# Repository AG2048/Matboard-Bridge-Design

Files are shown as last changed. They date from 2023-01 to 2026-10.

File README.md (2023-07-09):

# Matboard-Bridge-Design

Matboard bridge project for CIV102 - Structure and Material

For the final project of CIV102, students have to design a matboard bridge using limited materials. 

For this project, I developed the python code that models the bridge and calculates the failure load and thus the factor of safety. 

Inside the repository also includes the design report (which includes the designing and construction process), as well as the engineering drawings of the bridge.

For further information, https://civmin.utoronto.ca/bridge-testing-day-in-civ102-video/ includes the testing day of the bridge. (As of Jan 10 2023, the website only contains the testing information for 2021)

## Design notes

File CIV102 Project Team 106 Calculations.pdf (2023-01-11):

n | i

t

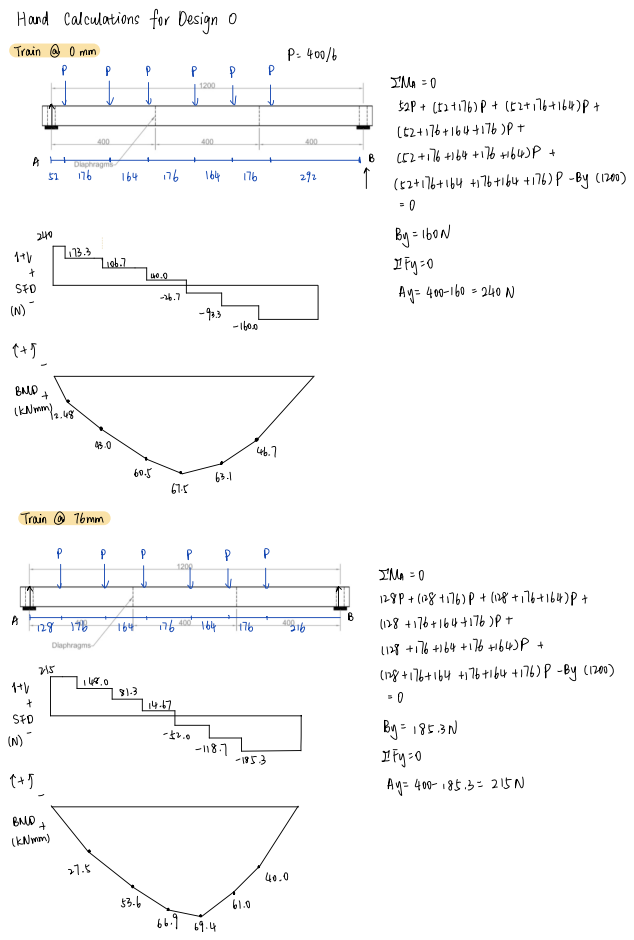
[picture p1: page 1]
Train 0mm; P ⁴⁰⁰6; SMA o; 528 15241761Pt152¹⁷⁶164Pt at; 152¹⁷⁶164176 Pt; gyp; 52176164 176164 176P By ¹²⁰⁰ D By¹⁶⁰N; IFyO; Ay⁴⁰⁰¹⁶⁰ ²⁴⁰N; boo; Mummies; Train 76mm; IMA O; B agent 1281176 164 176 164 176; Ay⁴⁰⁰¹⁸⁵.3 215N; Mimi; est

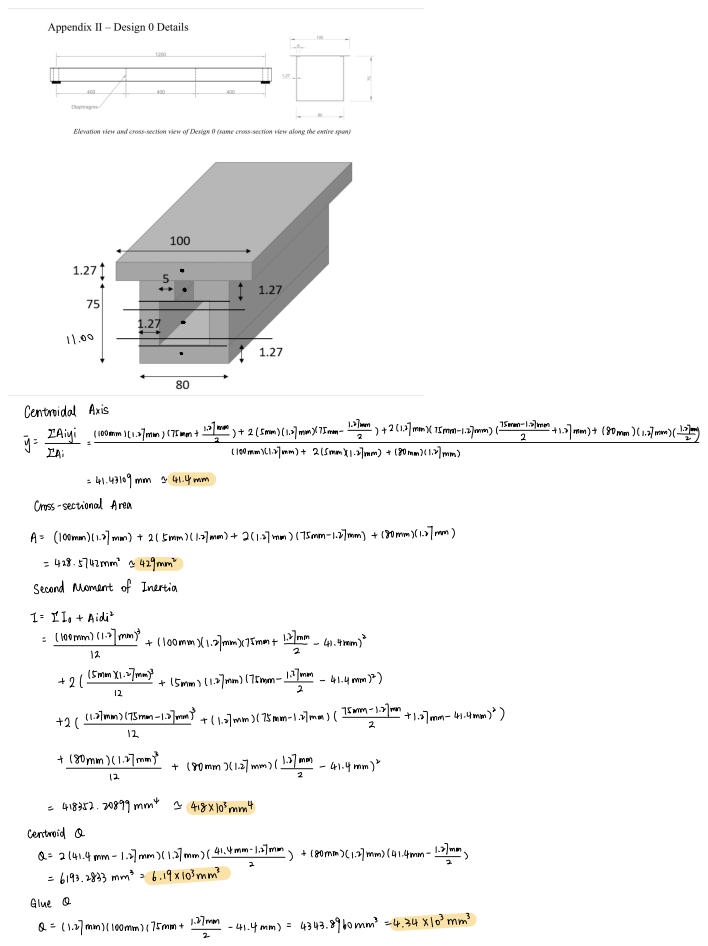
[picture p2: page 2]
entroidalAxis; cloommici 7mmit ²¹⁵mmiiiMmm isommici7mm; CrosssectionalArea; 7mm t 215mm 1.7mm 211.27mm175mm1.27mm isommill7mm; 428.5742mm a429mm secondMomentofInertia; IotAidi; 2 15mmill7mm is; 15mm 1.27mm175mm Imm 41.4mmp; 2 11.27mm lymm; gomm 1.27mm1171M 41.4mm; Centroid a a 2141.4mm 1.27mm 1.27mm 41.4mm l; Mmm; isommsci.ymmscai.amm t; Imm 2; 6193.2833mm 6.19103mm Glue a; 0 114mmilloomm175mm 12mm 41.4mm 4343.8960mm 4.34¹⁰³mm

175mmt Hamm 215mm111.4mm¹⁷⁵mm hmm 211.4mm1175mm1.27mm175mmt.mmtt.ymmitisommsci.ymmyl.my 2

ftp.iyi.lioommici.olmm

lloommsli.ofmmsatmmtt.LI 41.4mm

## as.am

### comp6hPa Tglue2hPa

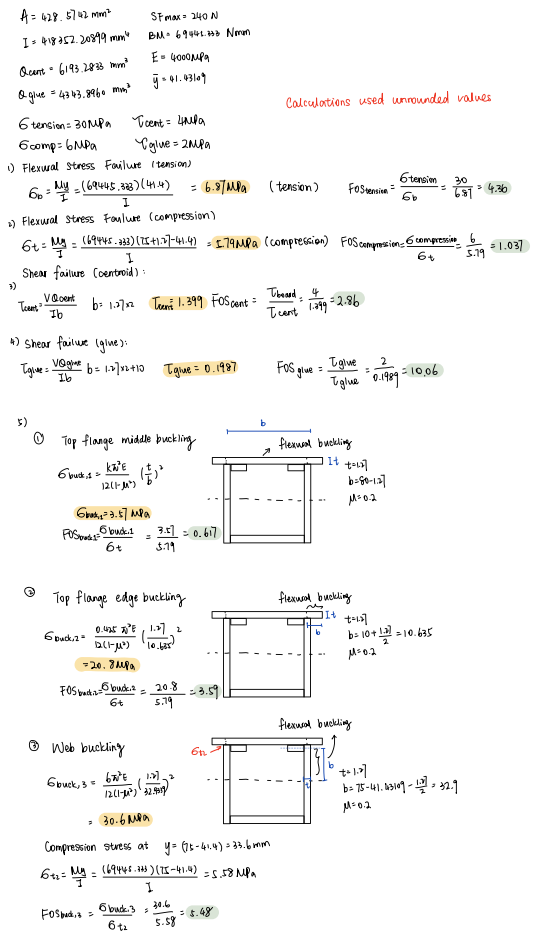
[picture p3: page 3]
BM⁶⁹⁴⁴⁵.333Nmm; E 4000hPa; I Acent 6193.2833mm; calculationsusedunroundedvalues; 6tension30hPa Tent 4hPa; 6 My169445.333714147 6.87hPa tension; Fostension; 6tension; a FlexuralstressFailure compression; 1.274141 5.79Mpa compression FOScompression6compression Eg ¹.037; Shearfailure centroid; Yg vÉg b; no igneous; insane Ige Easy10.06; topflangemiddlebuckling; flexuralbuckling; broin bucketEYEIf; It tan; Guns3.57hPa; FOSbuck.iq; may; back 1411 I p; byb; 20.8hPa www.qq; Webb; bas⁴¹.43109 Gun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

## toEYEfifiteal salma

### K5 a ³⁸⁵6 751.7

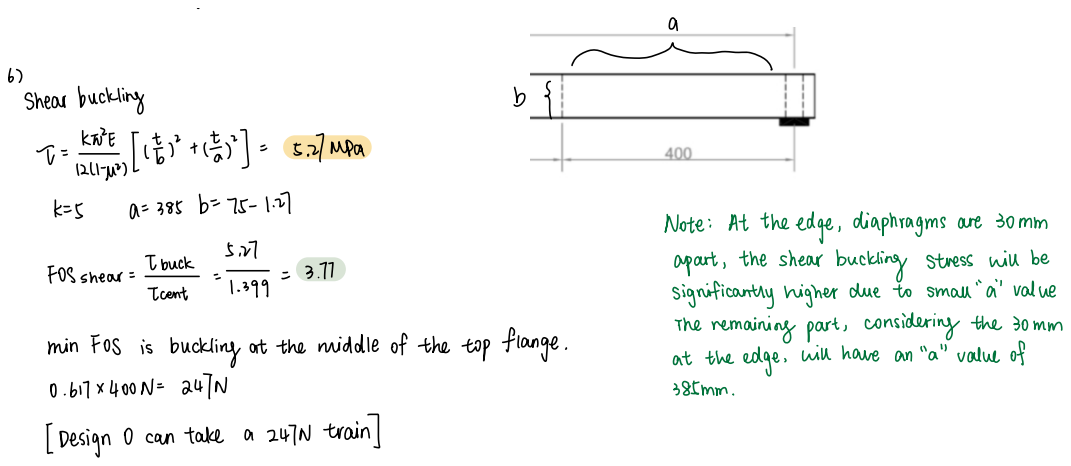
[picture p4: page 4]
shearbuckling; aparttheshearbuckling stresswillbe IOSshearIink; significantlyhigherduetosmall a value; Theremainingpart consideringthe30mm; minFos is bucklingatthemiddleofthetopflange; attheedgewinhavean a valueof

# Computer Output For Design 0

## Computer Output:

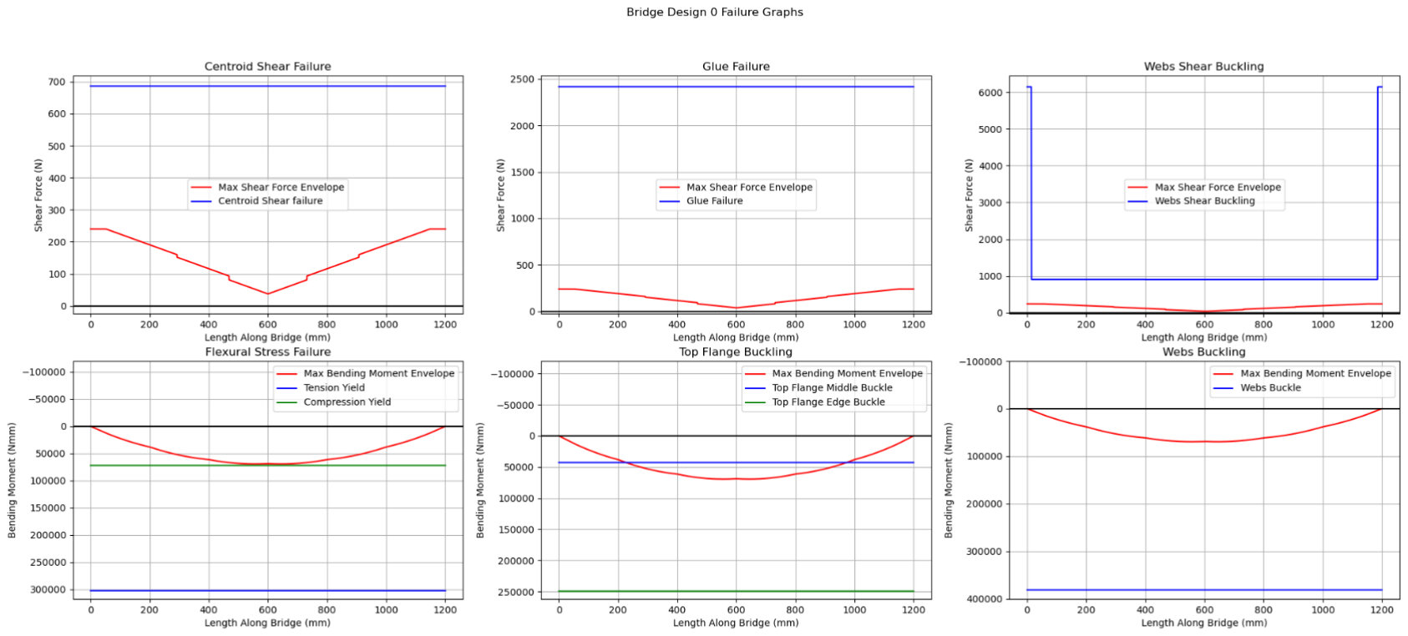
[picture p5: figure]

- Cross Sectional Area = 428.57419999999996 mm^2
- Second Moment of Area = 418352.20899942354 mm^4
- Q at centroid = 6193.283330576374 mm^3
- Q at glue = 4343.896017305755 mm^3
- Centroid Axis y = 41.43109435192319 mm
- Max compressive Flexural Stress At Top = 5.783163955284812 MPa
- Max Tensile Flexural Stress At Bottom = 6.877449421183901 MPa
- Max Shear Stress At Centroid = 1.3988025236519268 MPa
- Shear Stress At Glue = 0.19872433823234437 MPa
- Top Flange Middle Buckling Stress = 3.5669267268124725 MPa
- Top Flange Edge Buckling Stress = 20.769624320288845 MPa
- Webs Buckling Stress = 30.57591595827078 MPa
- Max Compressive Flexural Stress on Webs = 5.572347395849709 MPa
- Shear Buckling Stress on Webs Near Edge = 5.270341432147787 MPa

- Board shear FOS = 2.8595887785196377
- Glue failure FOS = 10.064192528152448
- Shear buckling FOS = 3.7677523045842327
- Tension FOS 4.362082243395943
- Compression FOS 1.0374943623234194
- Top flange middle buckling FOS 0.616777728314778
- Top flange edge buckling FOS 3.5913946899791767
- Webs buckling FOS 5.48708000169619

The maximum train load this bridge can hold is 246.7110913259 N

## Computer Output (Rounded):

- Cross Sectional Area = 429 mm^2
- Second Moment of Area = 418000 mm^4
- Q at centroid = 6190 mm^3
- Q at glue = 4340 mm^3
- Centroid Axis y = 41.4 mm
- Max compressive Flexural Stress At Top = 5.78 MPa
- Max Tensile Flexural Stress At Bottom = 6.88 MPa
- Max Shear Stress At Centroid = 1.399 MPa
- Shear Stress At Glue = 0.1987 MPa
- Top Flange Middle Buckling Stress = 3.57 MPa
- Top Flange Edge Buckling Stress = 20.8 MPa
- Webs Buckling Stress = 30.6 MPa
- Max Compressive Flexural Stress on Webs = 5.57 MPa
- Shear Buckling Stress on Webs Near Edge = 5.27 MPa
- Board shear FOS = 2.86
- Glue failure FOS = 10.06

- Shear buckling FOS = 3.77
- Tension FOS 4.36
- Compression FOS 1.037
- Top flange middle buckling FOS 0.617
- Top flange edge buckling FOS 3.59
- Webs buckling FOS 5.49

The maximum train load this bridge can hold is 247 N

# Calculations for Final Design

## Computer Output:

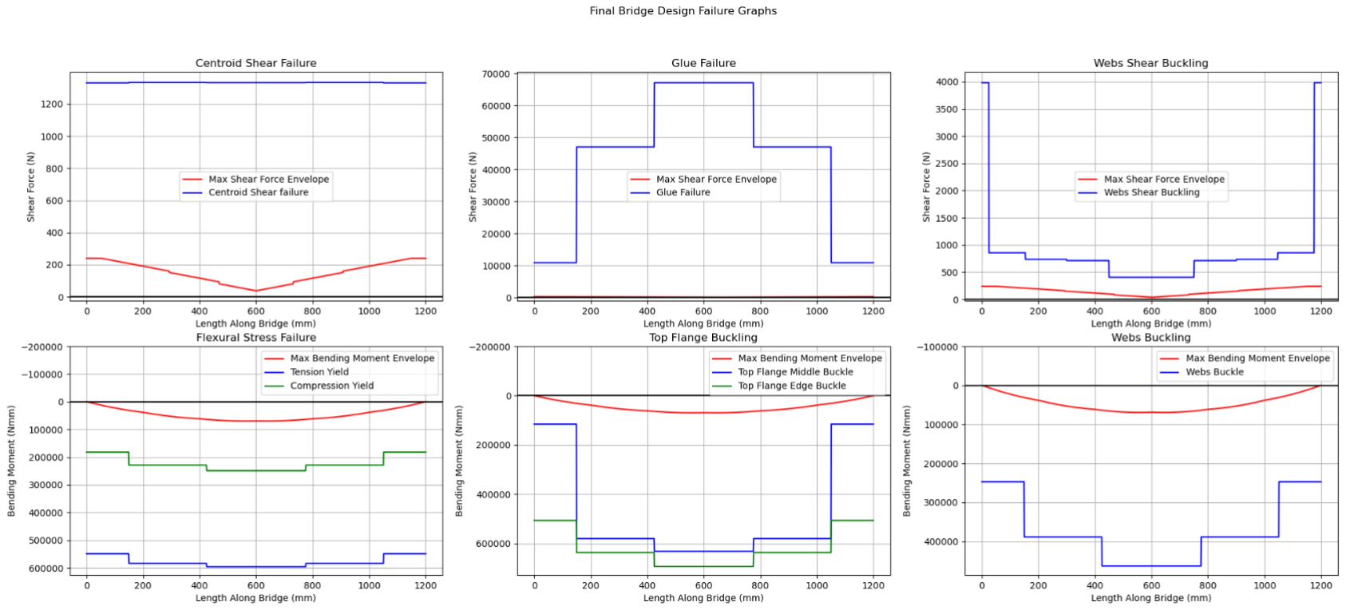
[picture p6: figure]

board shear FOS: 5.547303849577916 at x=0 glue failure FOS: 45.29755951143525 at x=0 shear buckling FOS: 3.5638078015539616 at x=25
tension FOS: 8.581376898757934 at x=556
compression FOS: 3.5863854774831045 at x=556
top flange middle buckle FOS: 3.7259908002777107 at x=1051
top flange edge buckle FOS: 9.974103289382535 at x=556
webs buckle FOS: 6.104646363211872 at x=424
- Minimum FOS is 3.5638078015539616 From Shear Buckling at x=25
- Max Train Load this bridge can support is: 1425.5231206215847 N

## Rounded Values:

board shear FOS: 5.55 at x=0
glue failure FOS: 45.3 at x=0 shear buckling FOS: 3.56 at x=25
tension FOS: 8.58 at x=556
compression FOS: 3.59 at x=556
top flange middle buckle FOS: 3.73 at x=1051
top flange edge buckle FOS: 9.97 at x=556
webs buckle FOS: 6.10 at x=424
- Minimum FOS is 3.56 From Shear Buckling at x=25
- Max Train Load this bridge can support is: 1426 N

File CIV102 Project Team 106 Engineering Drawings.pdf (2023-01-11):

# Note:

All images shown here are screenshots from AutoCAD. The resolution may be low because the drawings are to scale, and screenshots must fit the page. At the end of the document has the full-resolution drawings attached.

Board-cutting arrangements are only attached at the end of the file.

# Diagrams with see-through portions

## Elevation (Side) View

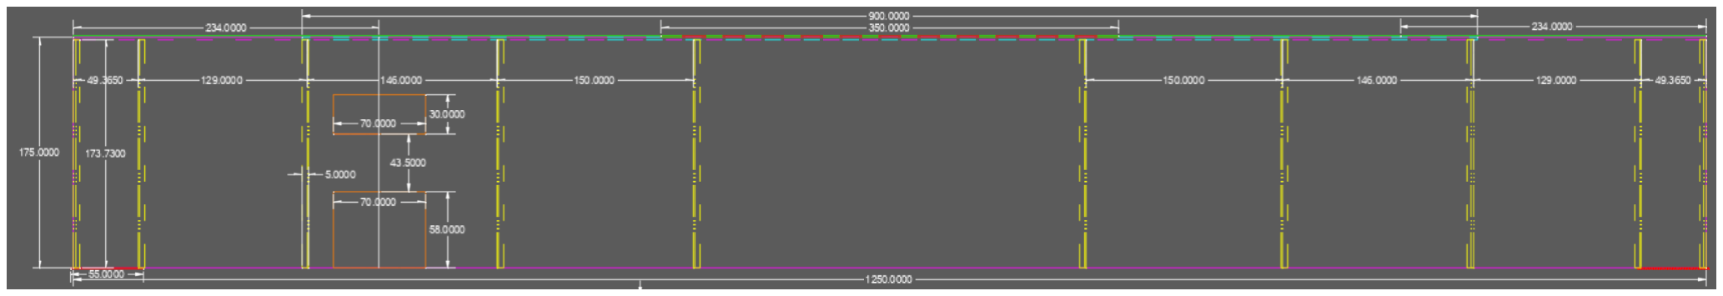
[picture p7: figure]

## Top and Bottom View

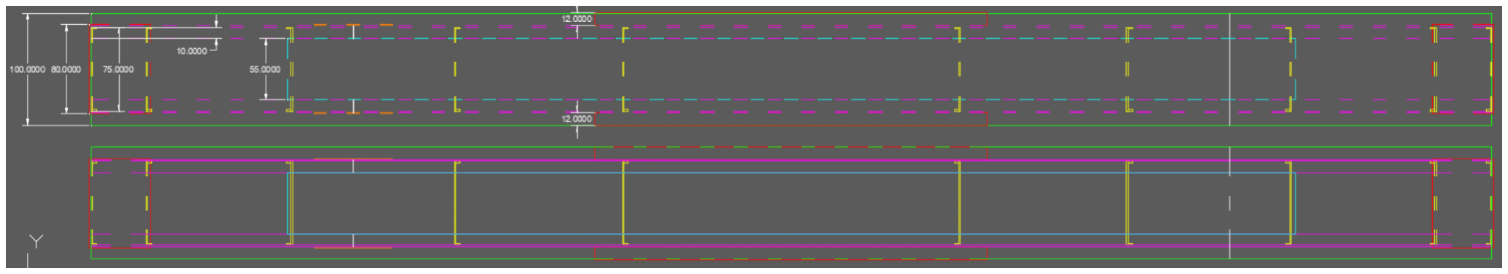
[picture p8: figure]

SOLID LINES = portion of the bridge that can be seen
DASH LINES = portion of the bridge that cannot be directly seen from the perspective Bridge is symmetrical with the exception of splice connections
All dimensions are given in mm
Board thickness is 1.27mm

Description:
- Yellow dash-dot lines are the main body of the diaphragms
- Yellow dash lines are the glue connection folded from the diaphragm boards
- Red lines at bottom are the bottom support plates
- Magenta lines are the side walls and portion of side walls folded in for glue connection to top board
- Orange lines are the pieces glued to side walls to secure splice connection of the side walls
- Cyan lines are the piece of additional board glued below the top board
- Red lines on top are for a small piece that extends out from the top of the board

- White lines that are not a part of the dimension indicators are the splice connections

# Diagrams without see-through portions

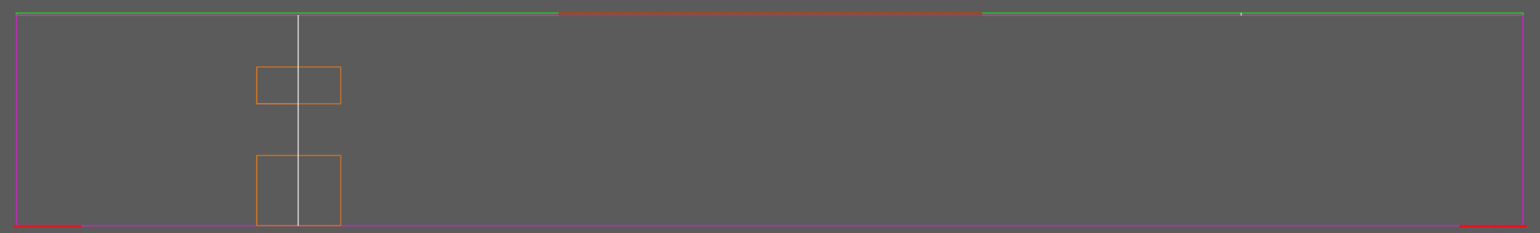
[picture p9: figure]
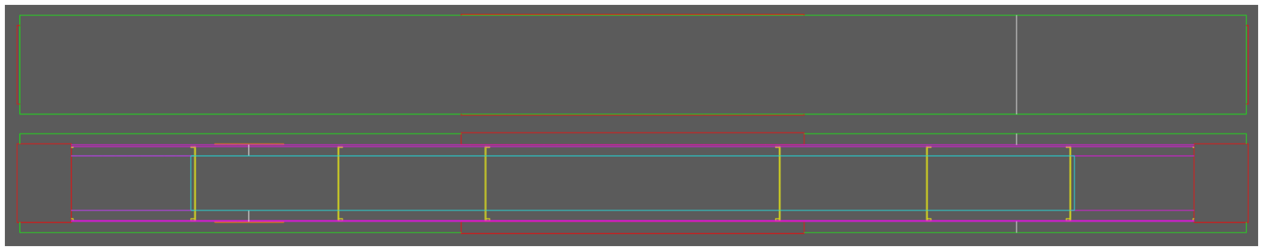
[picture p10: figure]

# Cross-Sections

## Edge of the bridge - with support bottom board and diaphragm

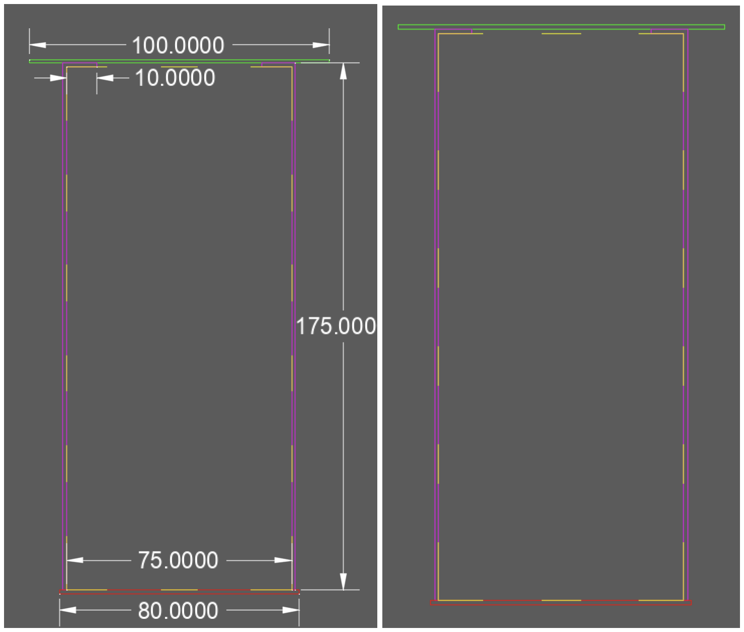
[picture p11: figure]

## Edge of the bridge - with support bottom board

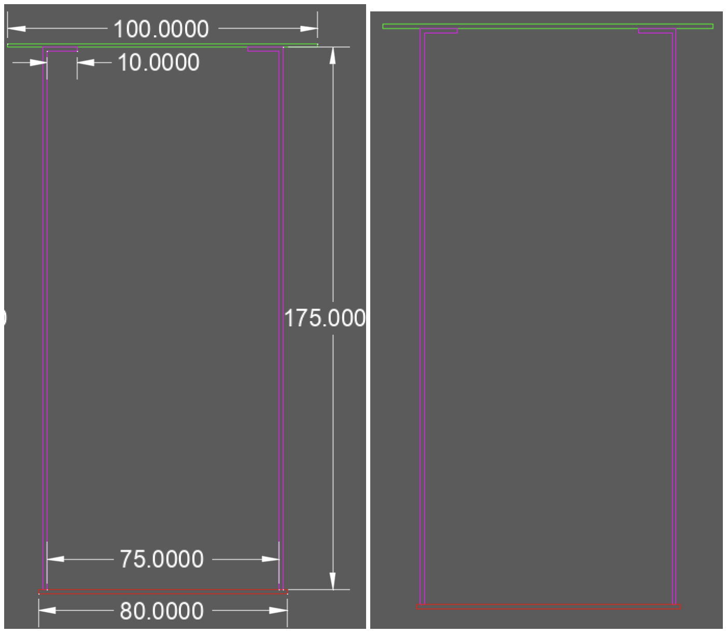
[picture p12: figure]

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
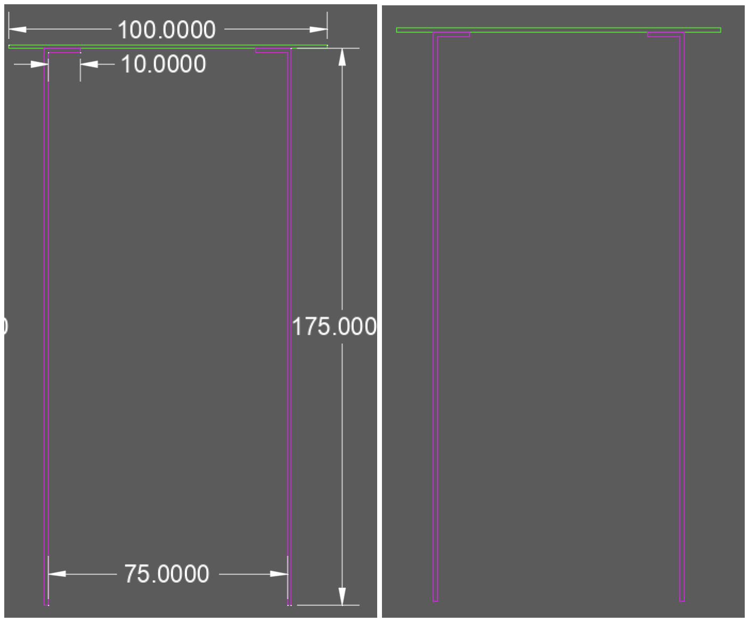
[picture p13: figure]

## Bridge with additional layer added to top board

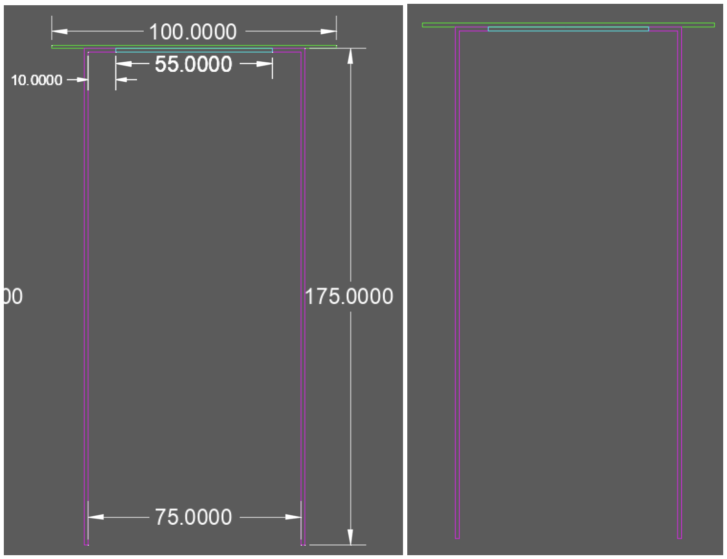
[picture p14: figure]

## Bridge with additional layer added to top board, and diaphragm

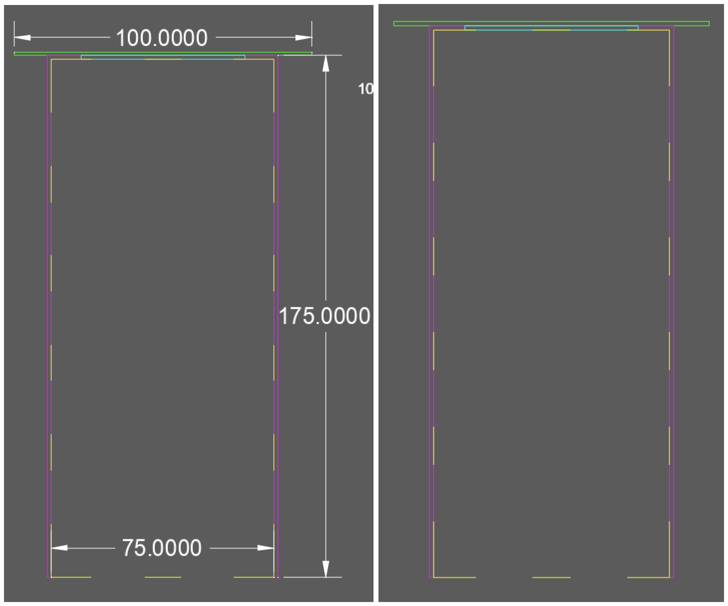
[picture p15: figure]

## Splice connection, with splice connectors glued to side walls

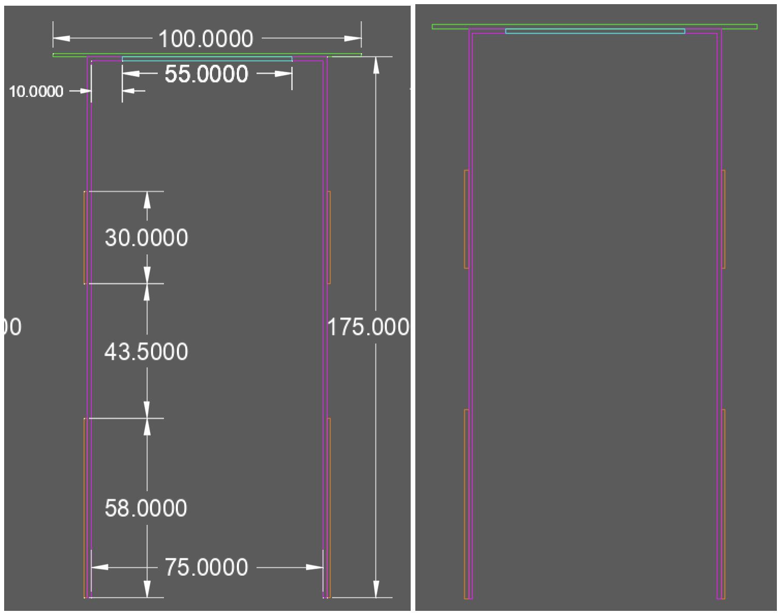
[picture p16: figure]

## Middle of the bridge with additional layer to top board and additional board to side of top board

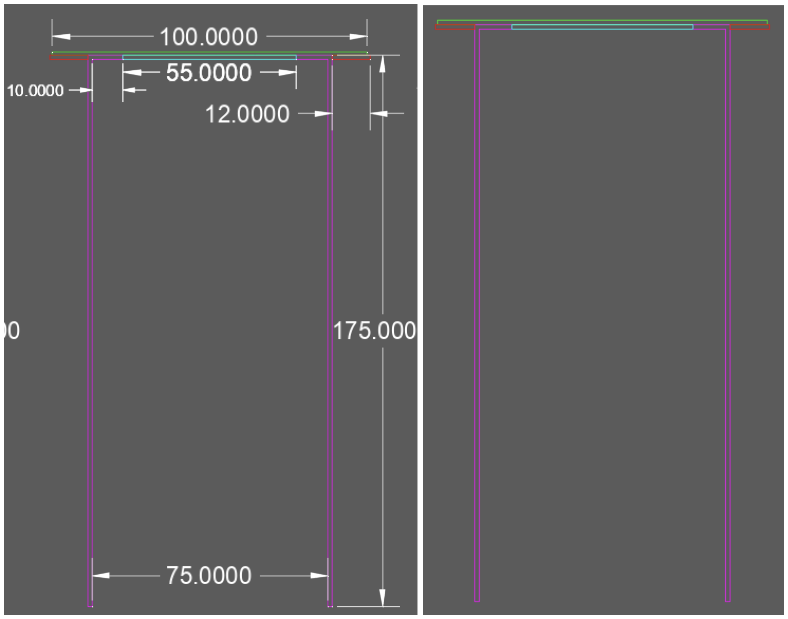
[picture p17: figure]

## Middle of the bridge with additional layer to top board and additional board to side of top board - including diaphragms

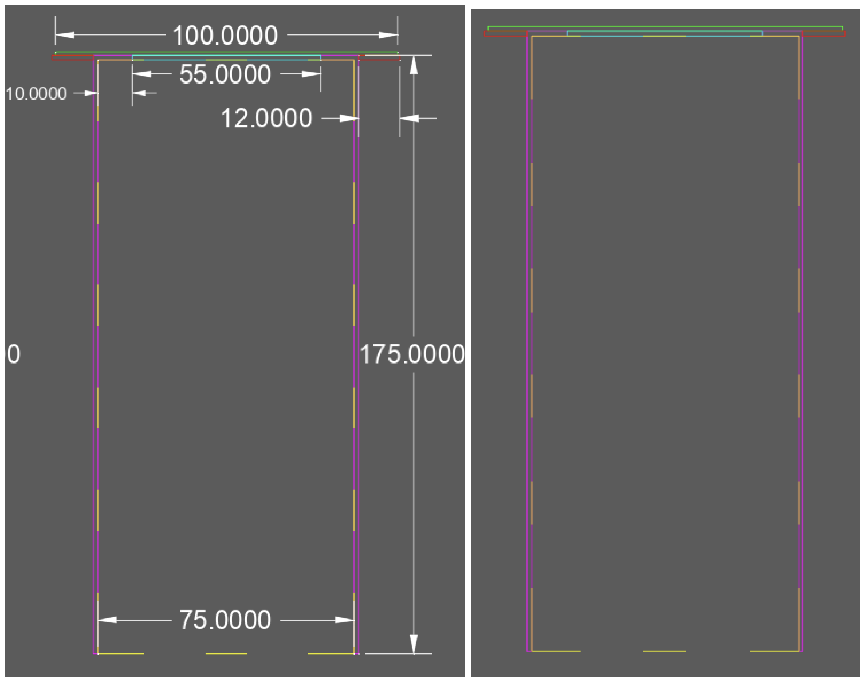
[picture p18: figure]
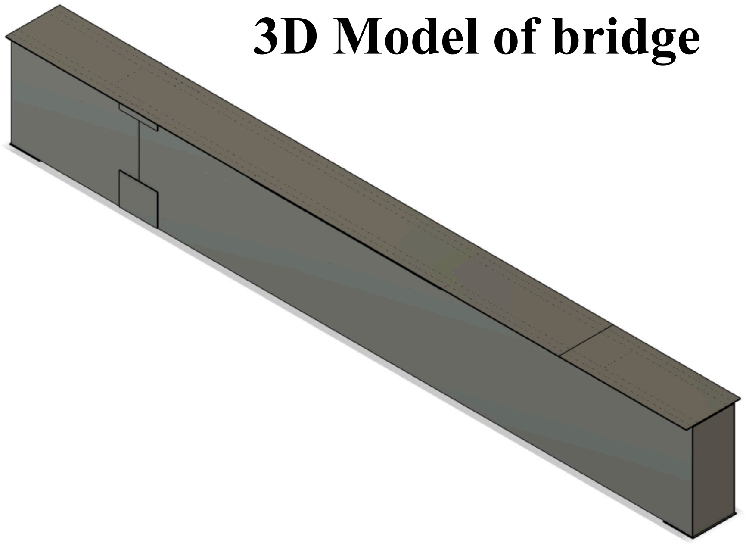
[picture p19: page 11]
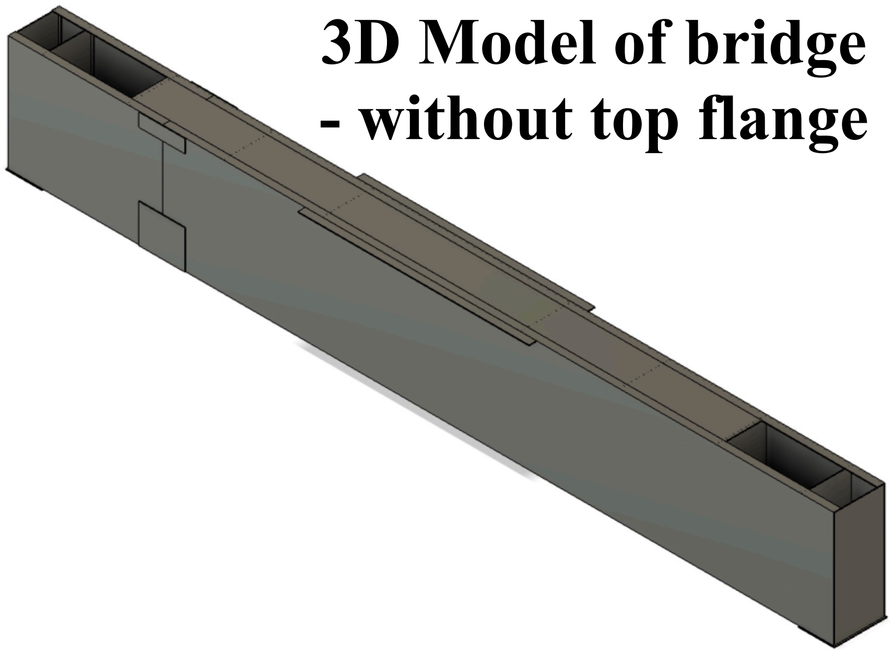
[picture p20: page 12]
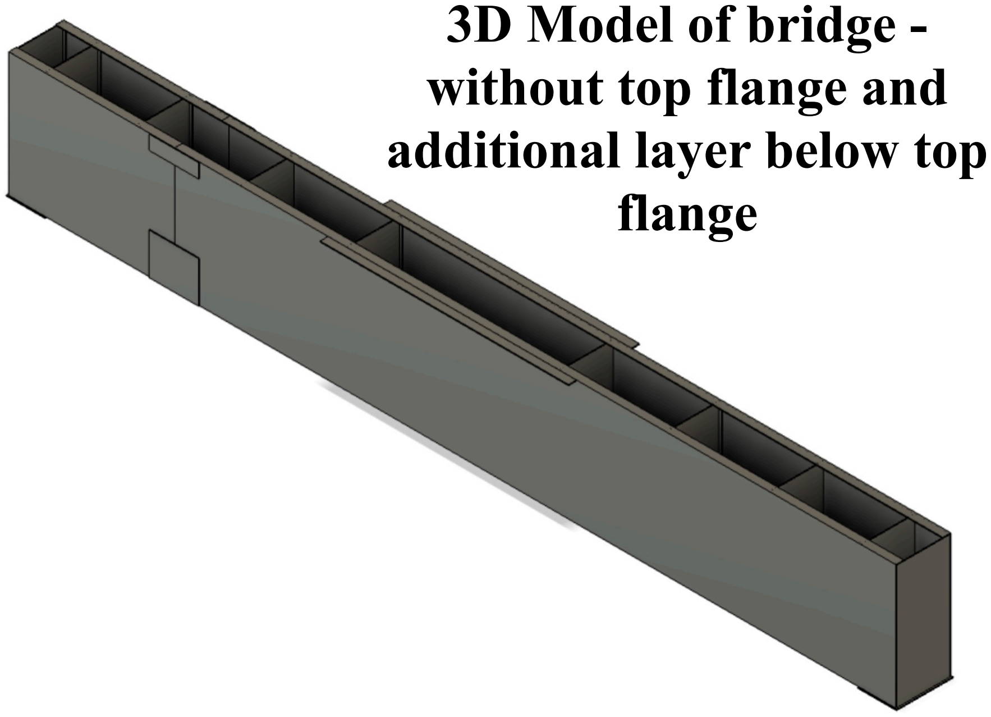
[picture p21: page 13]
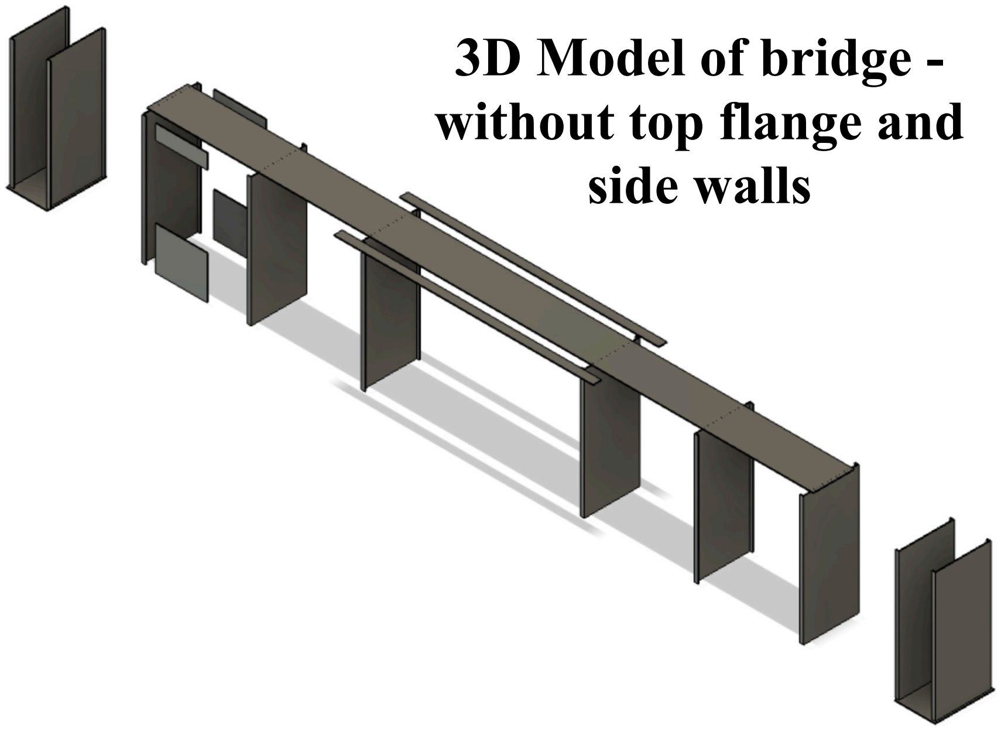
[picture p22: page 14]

# SIDE BOARD-LONG-A

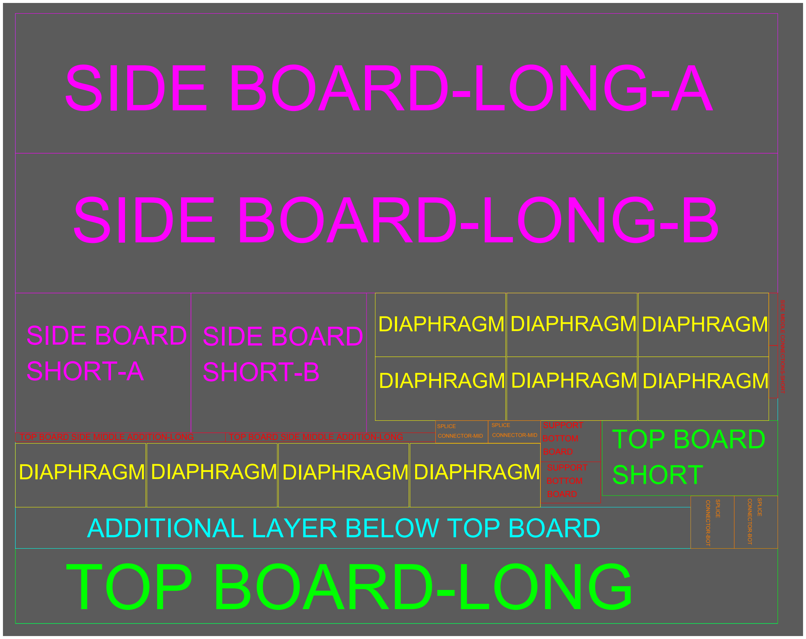
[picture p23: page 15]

# SIDE BOARD-LONG-B

# SIDE BOARD SHORT-A

# SIDE BOARD SHORT-B

# DIAPHRAGM DIAPHRAGM

# DIAPHRAGM DIAPHRAGM

# DIAPHRAGM

# DIAPHRAGM

# DIAPHRAGM DIAPHRAGM DIAPHRAGM DIAPHRAGM

# TOP BOARD-LONG

# TOP BOARD SHORT

# ADDITIONAL LAYER BELOW TOP BOARD

TOP BOARD SIDE MIDDLE ADDITION-LONG | TOP BOARD SIDE MIDDLE ADDITION-LONG

SPLICE
CONNECTOR-MID

SPLICE
CONNECTOR-MID

CONNECTOR-BOT

SPLICE

CONNECTOR-BOT

SPLICE

# SUPPORT BOTTOM BOARD

# SUPPORT BOTTOM BOARD

SIDE MIDDLE CONNECTIONS-SHORT

186.2700

1016.0000

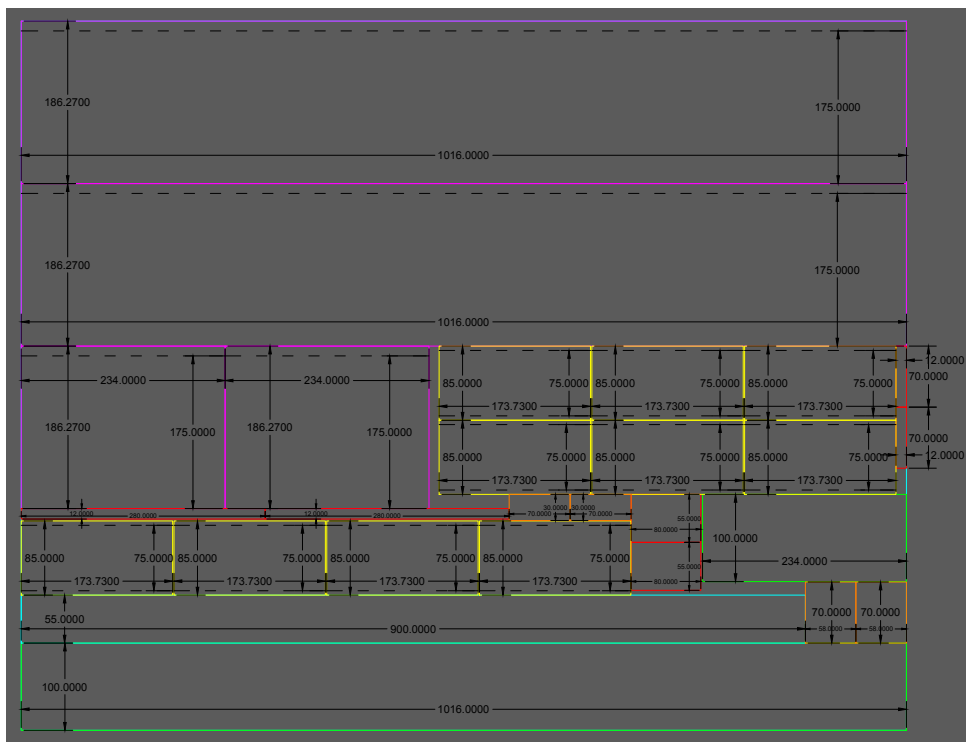
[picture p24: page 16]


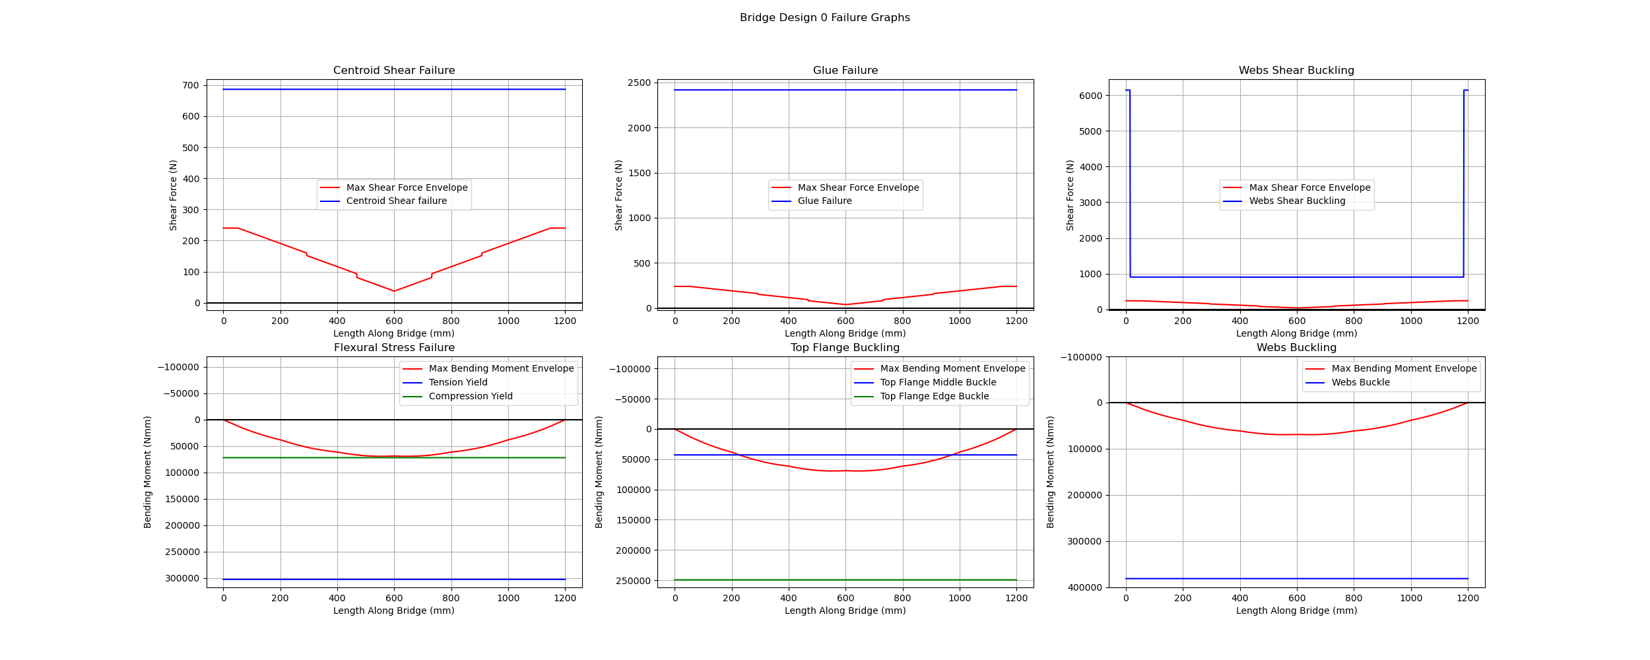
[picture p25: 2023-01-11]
Design 0.png

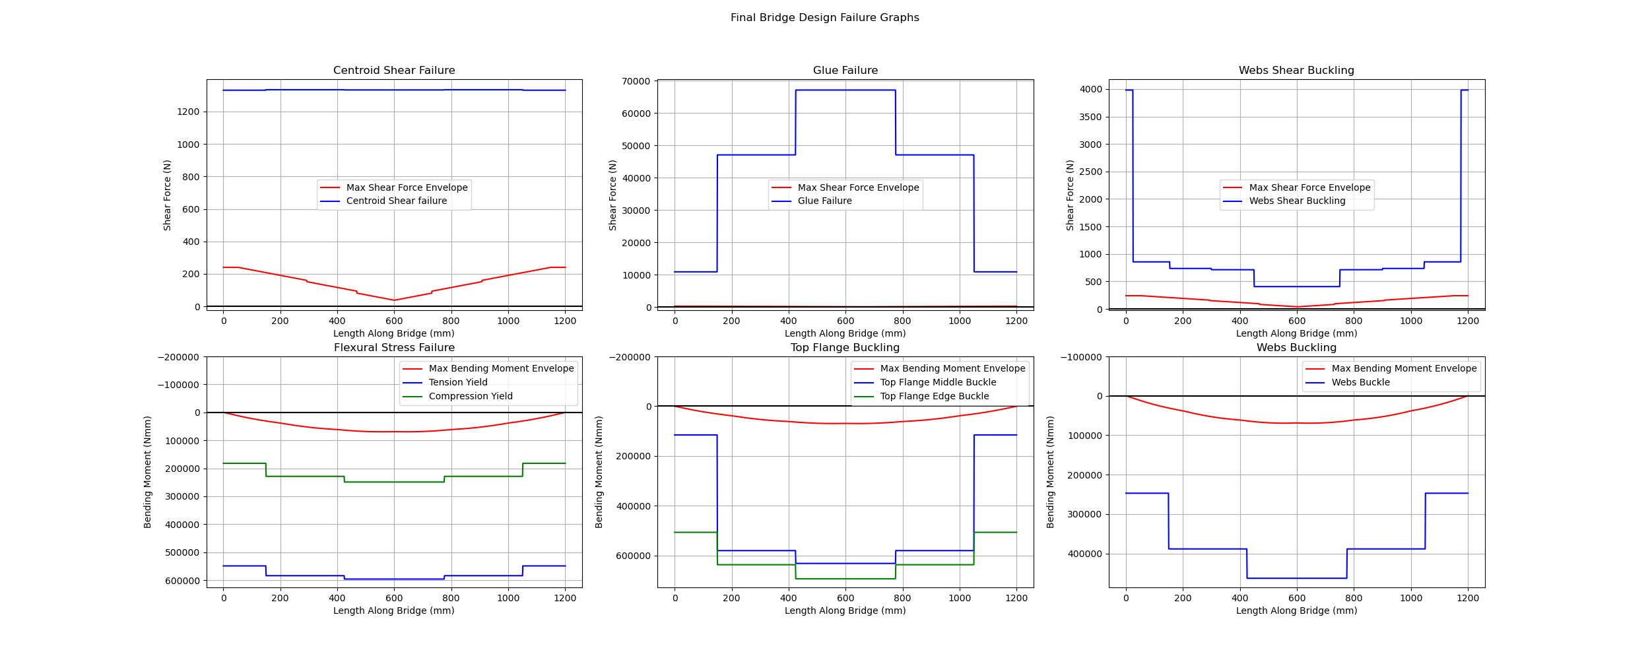
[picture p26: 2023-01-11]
Final Iteration.png

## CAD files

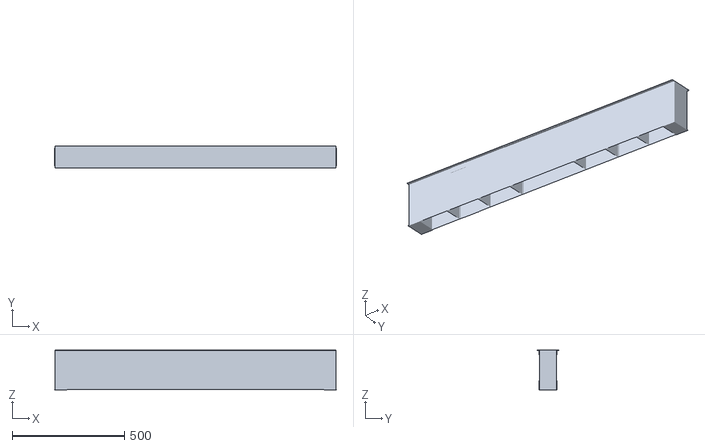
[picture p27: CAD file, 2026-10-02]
CIV102_Bridge.stl
1254.4 x 100.0 x 177.5
